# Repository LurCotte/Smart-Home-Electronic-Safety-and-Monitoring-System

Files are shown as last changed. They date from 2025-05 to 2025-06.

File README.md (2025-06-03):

# 🔌 Smart Home Electronic Safety and Monitoring System

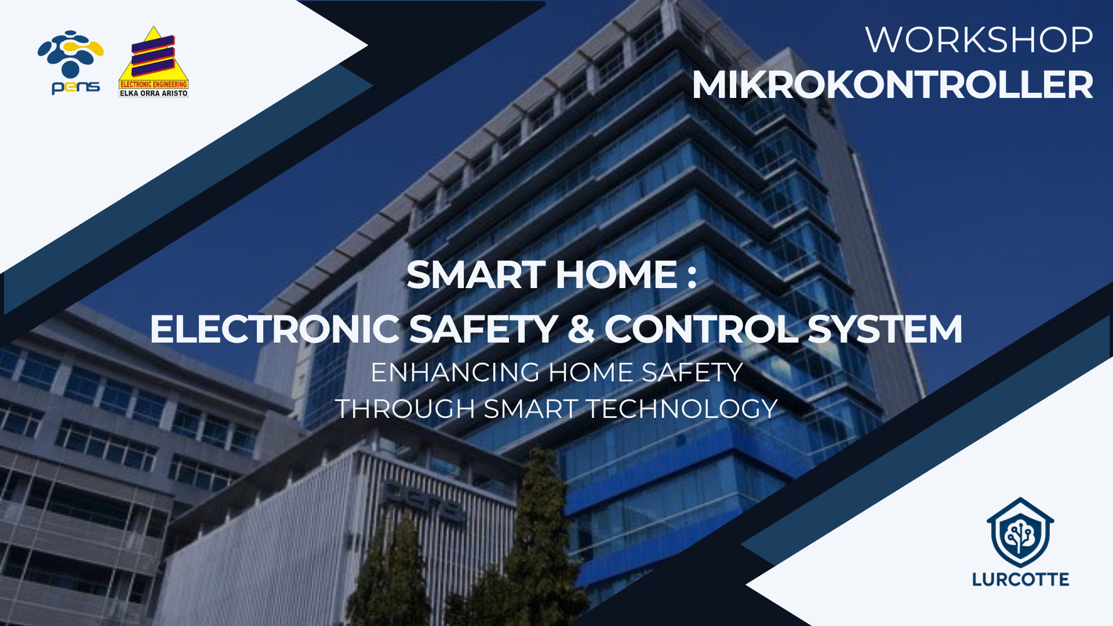
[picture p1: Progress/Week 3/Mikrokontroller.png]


## Team Member



## 📘 Deskripsi Proyek

Proyek ini bertujuan untuk mengembangkan **sistem automasi rumah pintar (Smart Home Automation System)** yang dapat memantau dan mengontrol peralatan elektronik secara real-time. Sistem ini juga dilengkapi dengan fitur **auto cut-off** untuk menjaga peralatan rumah tangga dari fluktuasi tegangan yang berasal dari jaringan listrik PLN.

## 🎯 Tujuan

- Mengontrol peralatan elektronik rumah secara dari satu titik pusat.
- Memantau konsumsi energi listrik dan menghitung biaya secara akurat.
- Melindungi perangkat dari overvoltage atau undervoltage melalui fitur auto cut-off.

## Video Iklan
https://vt.tiktok.com/ZSk2q9HfW/

## 🧠 Komponen Utama

| Komponen | Fungsi |
|---|---|
| Arduino Mega | Mikrokontroler utama yang mengatur komunikasi dan pengolahan data. |
| ACS712 | Sensor arus untuk mengukur konsumsi arus listrik. |
| ZMPT101B | Sensor tegangan AC untuk memantau tegangan dari sumber PLN. |
| Relay SPDT | Saklar untuk mengontrol perangkat listrik seperti lampu. |
| MCB 1 Phase | Proteksi arus lebih dan hubung singkat memutus aliran saat overload.  |
| Sensor Tambahan| Sensor-sensor lain untuk mendukung fungsi Smart Home tambahan. |

## 🔗 Komunikasi Sistem

Sistem menggunakan **komunikasi UART TTL** untuk mentransmisikan data antar perangkat dan sensor secara real-time. Arduino Mega memproses input dari sensor, lalu mengambil tindakan sesuai logika program.

## ⚡ Fitur Utama

- **Auto Cut-Off:** Memutus sambungan perangkat jika terjadi fluktuasi tegangan di luar ambang batas aman.
- **Monitoring Energi:** Penggunaan sensor ACS712 dan ZMPT101B untuk memantau konsumsi arus dan tegangan secara real-time.
- **Kontrol Perangkat Secara Terpusat:** Semua perangkat bisa dikontrol dari satu titik pusat melalui Komputer/laptop via UART.

## 🧩 Penjelasan Alur Sistem

- **Kabel fasa dan netral dari MCB PLN** terlebih dahulu masuk ke **input sensor ZMPT101B**. Sensor ini digunakan untuk membaca nilai tegangan dalam bentuk ADC (Analog to Digital Converter) yang kemudian akan diumpankan ke **pin analog mikrokontroler AVR**.

- **Mikrokontroler AVR** berkomunikasi dengan **laptop melalui komunikasi serial UART**, yang berfungsi sebagai antarmuka dan pusat kontrol untuk mengaktifkan atau menonaktifkan perangkat elektronik dari satu tempat.

- Pada **relay 5V**, pin **pole (common)** dihubungkan ke kabel fasa dari MCB PLN, pin **NO (Normally Open)** dihubungkan ke input MCB 1 phase, dan pin **coil** dihubungkan ke **pin output dari mikrokontroler AVR**.

- Jika **mikrokontroler AVR menerima perintah aktivasi dari laptop**, maka ia akan mengaktifkan pin output yang telah ditentukan, sehingga mengaktifkan relay dan menyebabkan perangkat elektronik menyala. Namun, hal ini hanya akan terjadi **jika tidak terdeteksi adanya fluktuasi tegangan atau hubung singkat**.

- **Perintah pengaktifan perangkat elektronik tidak akan diproses jika terjadi fluktuasi tegangan**, karena fungsi pendeteksi fluktuasi memiliki prioritas lebih tinggi. 

- Selain itu, jika terjadi **hubung singkat**, maka aktivasi perangkat tidak dapat dilakukan karena **MCB secara otomatis akan melakukan pemutusan arus (OFF)** untuk proteksi sistem.

- **Sensor ACS712** digunakan untuk membaca arus listrik yang kemudian akan digunakan untuk **perhitungan daya listrik (Watt)** secara real-time.

## 📊 Mind Map, Flowchart dan Diagram Blok

*Mind Map.*

Mind Map

*Flowchart.*

Flowchart Logika Kerja

*Diagram Blok Sistem.*

Diagram Hardware

*Tampilan GUI Python*

![Uploading 123.PNG…]()

## 🚀 Pengembangan Selanjutnya

- Integrasi dengan koneksi WiFi (ESP8266/ESP32) untuk kontrol via aplikasi mobile.
- Dashboard berbasis web untuk pemantauan konsumsi daya secara grafis.
- Otomatisasi berdasarkan waktu, cuaca, atau sensor gerak.

## 📁 Struktur Direktori (Opsional)
```bash
SmartHome-Automation/
│
├── src/                      # Kode program Arduino
├── images/                   # Diagram dan flowchart sistem
│   ├── block_diagram.png
│   └── flowchart_program.png
├── README.md                 # Dokumentasi proyek
└── docs/                     # Panduan penggunaan & pengembangan

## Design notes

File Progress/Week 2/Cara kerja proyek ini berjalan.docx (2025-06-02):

CARA KERJA

## 1. Sistem Awal & Setup

- Setelah sistem dinyalakan, Arduino Mega akan melakukan inisialisasi:
  - Mengatur pin sensor dan output (relay).
  - Menyiapkan komunikasi UART dengan laptop.
  - Menyiapkan ambang batas tegangan dan arus untuk proteksi.
- MCB PLN utama menyuplai listrik ke sistem (fase dan netral).

## 2. Pembacaan Data Sensor

### a. Sensor Tegangan (ZMPT101B)

- Membaca tegangan AC dari jaringan PLN.
- Tegangan diubah menjadi sinyal analog (0–5V) dan masuk ke pin analog Arduino.
- Arduino mengonversi data ADC menjadi nilai tegangan aktual (Volt).

### b. Sensor Arus (ACS712)

- Membaca arus yang mengalir ke perangkat rumah tangga.
- Arus dikonversi menjadi tegangan analog menggunakan efek Hall.
- Arduino membaca nilai ADC lalu menghitung arus aktual (Ampere).

## 3. Analisis & Proteksi Otomatis

Arduino menganalisis data sensor:

- Jika tegangan normal (misal 200V–240V) dan arus normal (misal < 6A):
  - Sistem dianggap aman → Siap aktifkan perangkat.
- Jika tegangan drop atau naik tajam (fluktuasi):
  - Sistem dianggap tidak aman → Relay tidak diaktifkan.
- Jika arus melebihi ambang batas (overload):
  - Arduino memutus relay → auto cut-off aktif.
- Jika terjadi short circuit:
  - MCB 1 Phase akan trip (OFF) dan memutus aliran listrik.
  - Arduino mendeteksi tidak ada arus → sistem dinonaktifkan.

## 4. Aktivasi Perangkat Elektronik

- Laptop mengirim perintah via UART: misalnya “AKTIFKAN”.
- Arduino akan memeriksa status tegangan & arus:
  - Jika aman, Arduino mengaktifkan relay SPDT (menghubungkan fase ke MCB 1 Phase).
  - Jika tidak aman, perintah diabaikan dan relay tetap OFF.

## 5. Monitoring Real-Time

- Arduino secara berkala mengirimkan data ke laptop:
  - Tegangan (Volt)
  - Arus (Ampere)
  - Daya (Watt = V × I)
  - Status sistem (AMAN / BAHAYA)
- Data bisa ditampilkan dalam bentuk teks atau grafik.

## 6. Kondisi Abnormal atau Emergency

- Jika sewaktu-waktu tegangan berubah drastis atau arus melonjak:
  - Arduino langsung mematikan relay (proteksi otomatis).
  - MCB 1 Phase memutus arus jika terdeteksi short circuit.
  - Sistem tidak bisa diaktifkan ulang sampai MCB dinyalakan manual.

## Kesimpulan Cara Kerja Sistem:

- Sistem mendeteksi, menganalisis, dan mengontrol perangkat elektronik secara otomatis dan real-time.
- Proteksi otomatis berbasis sensor dan MCB mencegah kerusakan peralatan.
- Kendali terpusat via laptop membuat sistem lebih fleksibel dan canggih.
- Kombinasi Arduino, sensor, relay, dan MCB menjadikan sistem ini efisien, aman, dan cocok untuk smart home masa kini.

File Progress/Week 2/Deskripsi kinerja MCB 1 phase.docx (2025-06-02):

### Deskripsi Komponen: MCB 1 Phase

MCB (Miniature Circuit Breaker) 1 Phase adalah komponen proteksi listrik yang berfungsi memutus arus listrik secara otomatis jika terjadi:

- Kelebihan arus (overload)
- Hubung singkat (short circuit)

Dalam sistem, MCB berperan sebagai proteksi lapisan terakhir terhadap kondisi berbahaya, melengkapi proteksi otomatis dari Arduino dan relay.

Fungsi MCB 1 Phase dalam system :

1. Memutus Arus Saat Bahaya:
  - Jika arus melebihi kapasitas (misal >6A untuk MCB 6A), MCB akan trip (OFF) secara otomatis.
  - Jika terjadi short circuit, MCB langsung memutus jalur fasa dalam waktu milidetik.
2. Melindungi Perangkat Rumah Tangga:
  - Mencegah kerusakan perangkat akibat arus berlebih.
  - Mencegah potensi kebakaran akibat korsleting listrik.
3. Integrasi dengan Sistem Otomatis:
  - Ditempatkan setelah output relay dan sebelum perangkat elektronik.
  - Jika MCB trip, Arduino akan mendeteksi bahwa tidak ada arus atau status sistem OFF, dan menonaktifkan relay untuk mencegah percikan listrik saat recovery.

### Kelebihan MCB:

- Cepat merespon bahaya listrik
- Mudah di-reset secara manual
- Tidak perlu diganti setelah trip (beda dengan sekering)
- Menjadi proteksi akhir jika kontrol otomatis gagal

### Contoh Kinerja MCB dalam Proyekmu:

Misalnya:

1. Arduino mendeteksi arus 2A dan tegangan 220V → relay ON.
2. Perangkat menyala, lalu terjadi korsleting karena kabel rusak.
3. Arus melonjak menjadi 15A dalam waktu singkat.
4. MCB 6A langsung memutus arus, sistem menjadi aman.
5. Arduino membaca arus = 0A → menandakan bahwa MCB OFF.
6. Sistem tidak mengaktifkan ulang perangkat sebelum dicek ulang manual.

### Kesimpulan:

MCB 1 Phase adalah komponen penting dan wajib dalam sistem smart home berbasis Arduino. Meskipun sistem sudah otomatis (menggunakan sensor dan relay), MCB menjadi pertahanan terakhir jika terjadi kondisi darurat kelistrikan. Ia menjaga agar tidak ada arus berbahaya yang mengalir ke perangkat dan rumah — sehingga keselamatan tetap terjaga

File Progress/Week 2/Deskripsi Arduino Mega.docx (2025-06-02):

Deskripsi Komponen: Arduino Mega 2560

Arduino Mega berperan sebagai otak utama sistem. Semua proses pengambilan data, pengambilan keputusan, serta kontrol perangkat elektronik dilakukan oleh mikrokontroler ini. Karena memiliki banyak pin I/O dan memori besar, Arduino Mega sangat cocok untuk proyek kompleks seperti smart home yang melibatkan banyak sensor dan aktuator.

Fungsi utama Arduino Mega :

1. Membaca Sensor:
  - Menerima data tegangan dari sensor ZMPT101B (pin analog).
  - Menerima data arus listrik dari ACS712 (pin analog).
  - Dapat membaca sensor tambahan (LDR, suhu, PIR, dll) jika diperlukan.
2. Memproses Data:
  - Mengubah sinyal analog dari sensor menjadi data numerik.
  - Menghitung nilai tegangan, arus, dan daya (Watt).
  - Membandingkan nilai tersebut dengan ambang batas aman.
3. Mengambil Keputusan:
  - Jika tegangan dan arus normal, Arduino mengaktifkan relay untuk menyalakan perangkat.
  - Jika tegangan tidak stabil (drop/spike) atau arus berlebih, Arduino menonaktifkan relay (cut-off).
  - Jika terjadi short circuit dan MCB trip, Arduino mendeteksi perubahan status dan mematikan sistem untuk proteksi.
4. Kontrol Aktuator:
  - Memberi sinyal ke relay SPDT (melalui pin digital) untuk ON/OFF arus ke peralatan.
  - Dapat dikembangkan untuk mengontrol lampu, kipas, charger, dll.
5. Komunikasi Serial ke Laptop (UART):
  - Mengirim data real-time seperti:
    - Tegangan (Volt)
    - Arus (Ampere)
    - Daya (Watt)
    - Status sistem (ON/OFF, Aman/Bahaya)
  - Menerima perintah aktivasi dari laptop (misal: menyalakan atau mematikan perangkat).
  - Dapat digunakan untuk logging data atau visualisasi grafik.\

Peran Arduino Mega :

- Menjadi pusat keputusan proteksi otomatis (cut-off saat kondisi berbahaya).
- Memastikan keamanan perangkat elektronik dan penghuni rumah.
- Bisa dikembangkan lebih lanjut untuk integrasi IoT (dengan modul ESP8266/ESP32 sebagai penghubung).

Contoh proses :

1. Arduino membaca tegangan = 230V → OK.
2. Arduino membaca arus = 2.3A → OK.
3. Arduino hitung daya = 529W → OK.
4. Arduino menerima perintah ON → Mengaktifkan relay.
5. Jika tiba-tiba tegangan drop ke 170V → Arduino OFF-kan relay → Sistem terlindungi.

Kesimpulan :

Arduino Mega bertindak sebagai unit pusat pengontrol dan pengolah data. Ia mengoordinasikan semua komponen mulai dari sensor input, pengambilan keputusan berbasis logika keamanan, hingga eksekusi kontrol terhadap perangkat elektronik. Arduino Mega memastikan sistem smart home ini menjadi otomatis, aman, dan dapat dimonitor secara real-time.

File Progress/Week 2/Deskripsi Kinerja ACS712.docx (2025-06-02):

Deskripsi Komponen: ACS712 dalam Sistem

Sensor ACS712 merupakan sensor arus berbasis efek Hall yang digunakan untuk mengukur arus listrik AC maupun DC secara aman dan real-time. Dalam sistemmu, ACS712 berfungsi untuk memantau arus konsumsi listrik dari peralatan rumah tangga yang sedang menyala. Data arus ini kemudian digunakan untuk:

- Menghitung daya listrik (dengan kombinasi data tegangan dari ZMPT101B).
- Melakukan proteksi terhadap arus berlebih (overload).
- Monitoring status konsumsi daya secara serial ke laptop.

Fungsi utama dalam system :

- Mengukur besar arus yang mengalir melalui jalur fasa setelah relay dan sebelum perangkat elektronik.
- Menghasilkan tegangan analog (sekitar 0–5V) yang proporsional terhadap arus yang mengalir.
- Memberikan input ke pin analog Arduino (misal A1) untuk diolah dan dianalisis.
- Jika arus melebihi ambang batas aman, sistem akan menonaktifkan relay (cut-off otomatis).

Cara kerja ACS712 :

1. Arus listrik dari fasa melewati jalur input/output di sensor ACS712.
2. Efek Hall di dalam sensor mendeteksi medan magnet yang muncul akibat arus, lalu mengubahnya menjadi tegangan analog.
3. Tegangan ini biasanya berpusat di 2.5V saat arus = 0A.
4. Arduino membaca nilai tegangan analog, lalu menghitung arus aktual (positif/negatif).
5. Nilai arus digunakan untuk:
  - Menghitung daya (Watt) → daya = arus × tegangan.
  - Proteksi → jika arus melebihi ambang batas, maka sistem memutus aliran (relay OFF).

Kelebihan penggunaan ACS712 :

- Dapat mengukur arus AC dan DC (meskipun proyekmu fokus ke AC).
- Aman karena tidak menghubungkan langsung kabel ke ADC, hanya sinyal tegangan.
- Ukuran kompak dan langsung kompatibel dengan Arduino.
- Tersedia dalam beberapa varian: 5A, 20A, 30A (dengan sensitivitas berbeda).

Kesimpulan peran ACS712 :

Sensor ini berperan penting dalam deteksi arus aktual, perhitungan konsumsi daya, serta fungsi proteksi arus lebih. Dengan ACS712, sistem bisa memastikan perangkat tidak digunakan melebihi kapasitas, dan memutus aliran jika arus yang terdeteksi tidak wajar — mencegah risiko kebakaran atau kerusakan peralatan.

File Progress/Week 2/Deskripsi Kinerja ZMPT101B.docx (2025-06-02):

Deskripsi Komponen: ZMPT101B dalam Sistem

Sensor ZMPT101B merupakan sensor yang dirancang khusus untuk mengukur tegangan AC dari jaringan listrik (seperti PLN) secara aman dan terisolasi. Dalam sistem ini, ZMPT101B digunakan untuk memantau fluktuasi tegangan secara real-time, sehingga sistem dapat mengambil keputusan otomatis untuk mengaktifkan atau menonaktifkan perangkat elektronik demi keselamatan.

Fungsi utama dalam system :

- Mengukur tegangan AC PLN (biasanya 220V) dan mengubahnya menjadi sinyal analog (0–5V).
- Memberikan input analog ke mikrokontroler (Arduino Mega) melalui pin analog (misal A0).
- Data tegangan digunakan untuk:
  - Monitoring di laptop melalui komunikasi UART.
  - Logika auto cut-off: memutus aliran listrik ke perangkat jika tegangan di luar batas aman (misalnya <180V atau >250V)

Cara kerja ZMPT101B :

1. Kabel fasa dan netral dari MCB PLN disambungkan ke input sensor ZMPT101B.
2. ZMPT menggunakan trafo kecil di dalamnya untuk menurunkan tegangan AC tinggi menjadi sinyal AC rendah.
3. Sinyal ini kemudian diolah oleh rangkaian pembagi tegangan dan penyearah untuk menghasilkan sinyal analog yang bisa dibaca oleh pin ADC Arduino.
4. Arduino membaca nilai ADC, lalu menghitung nilai tegangan aktual dengan rumus kalibrasi.
5. Nilai ini digunakan untuk monitoring, serta sebagai syarat pengaktifan relay (hanya jika tegangan dalam batas normal).

Kelebihan penggunaan ZMPT101B :

- Aman: Terisolasi dari tegangan tinggi (pakai trafo isolasi).
- Akurasi cukup baik untuk aplikasi monitoring rumah tangga.
- Output linier yang cocok untuk pembacaan ADC oleh mikrokontroler.
- Mudah dikalibrasi dan kompatibel langsung dengan Arduino.

Kesimpulan peran ZMPT101B :

Sensor ini berperan kritis sebagai detektor kesehatan tegangan dari jaringan listrik PLN. Tanpa sensor ini, sistem tidak dapat mendeteksi fluktuasi yang berbahaya dan berpotensi merusak perangkat rumah tangga. Dengan ZMPT101B, sistem menjadi lebih cerdas dan aman karena dapat mengambil tindakan preventif secara otomatis.

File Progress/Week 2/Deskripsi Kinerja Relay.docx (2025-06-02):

Deskripsi Komponen: Relay SPDT dalam Sistem

Relay SPDT (Single Pole Double Throw) berperan penting sebagai saklar elektronik dalam sistem ini. Komponen ini memungkinkan Arduino Mega untuk mengontrol sambungan atau pemutusan aliran listrik ke peralatan rumah tangga secara otomatis berdasarkan hasil pemantauan tegangan dan arus.

#### Fungsi dalam Sistem:

Relay berfungsi sebagai penghubung atau pemutus jalur fasa dari sumber listrik ke perangkat elektronik yang akan dikendalikan. Dengan kontrol dari mikrokontroler, relay memastikan bahwa peralatan hanya menyala ketika kondisi listrik aman (tegangan stabil dan tidak ada arus lebih).

#### Konfigurasi Koneksi:

- Pin COM (Common / Pole): Terhubung ke kabel fasa dari MCB PLN.
- Pin NO (Normally Open): Terhubung ke input MCB 1 phase, yang kemudian mengalirkan listrik ke perangkat rumah tangga.
- Pin NC (Normally Closed): Tidak digunakan dalam sistem ini.
- Pin Coil (+/-): Terhubung ke pin digital Arduino Mega (untuk kendali ON/OFF), dan satu sisi ke GND atau sumber 5V (melalui transistor jika perlu).

#### Cara Kerja di Sistem:

1. Saat Arduino tidak memberi sinyal, kontak COM dan NO terputus, sehingga arus tidak mengalir ke perangkat.
2. Jika tegangan dan arus terdeteksi dalam kondisi normal, dan perintah aktivasi diterima dari laptop, Arduino mengirimkan sinyal ke coil relay.
3. Relay pun menutup kontak antara COM dan NO, menyebabkan arus mengalir ke perangkat elektronik.
4. Jika terjadi fluktuasi tegangan atau hubung singkat, Arduino menonaktifkan relay, memutuskan aliran listrik secara otomatis demi proteksi sistem.

#### Keunggulan Penggunaan Relay SPDT:

- Mampu mengontrol beban AC dari sinyal logika DC (dari Arduino).
- Memberi isolasi antara rangkaian kontrol (low voltage) dan daya tinggi (PLN).
- Dapat diatur secara otomatis berdasarkan logika kondisi sistem (aman/tidak aman).
- Fail-safe: Jika tidak ada sinyal (misal Arduino mati), perangkat tetap dalam kondisi mati karena jalur NO terbuka.

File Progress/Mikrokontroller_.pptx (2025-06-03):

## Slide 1

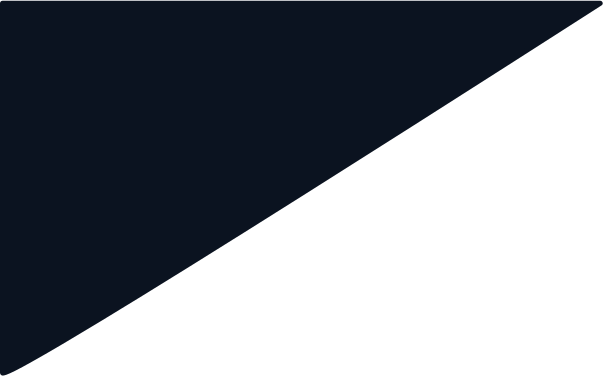
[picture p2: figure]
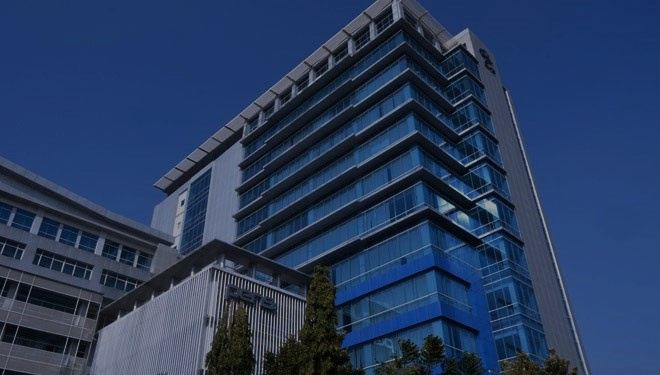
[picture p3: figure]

SMART HOME :
ELECTRONIC SAFETY & CONTROL SYSTEM

ENHANCING HOME SAFETY THROUGH SMART TECHNOLOGY

WORKSHOP

MIKROKONTROLLER

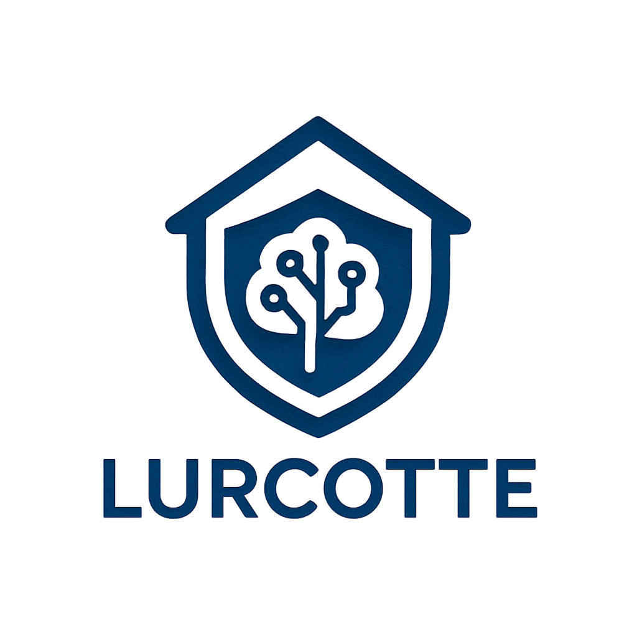
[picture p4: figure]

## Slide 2

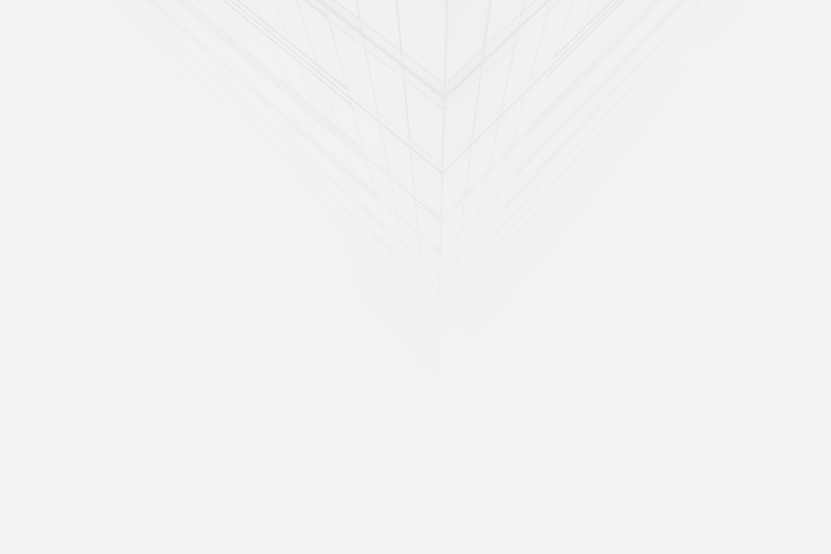
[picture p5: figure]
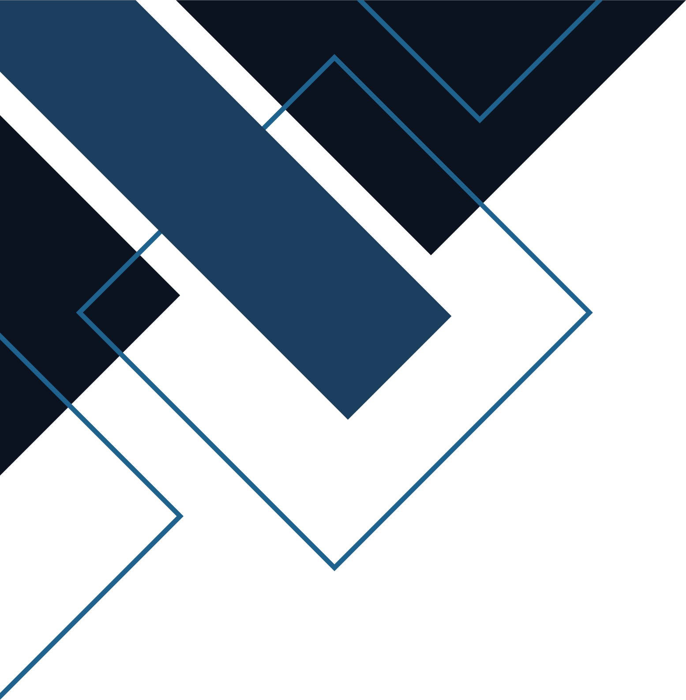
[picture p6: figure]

DOSEN PEMBIMBING

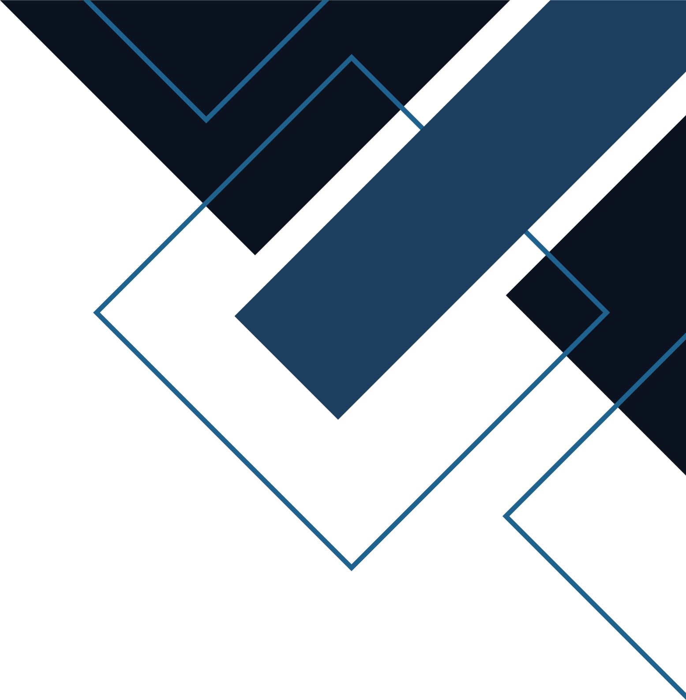
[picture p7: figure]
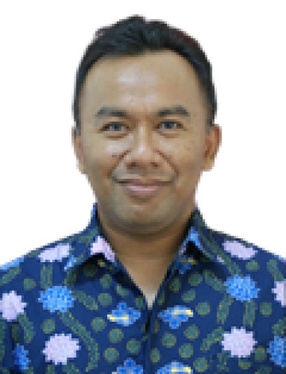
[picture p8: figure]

AKHMAD HENDRIAWAN, S.T, M.T
197501272002121003

LURCOTTE MEMBER

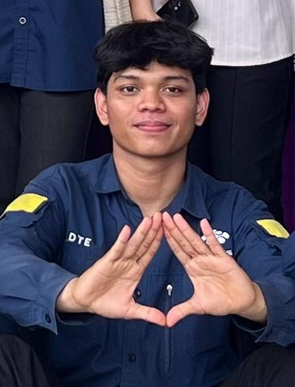
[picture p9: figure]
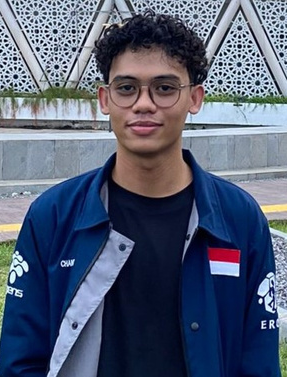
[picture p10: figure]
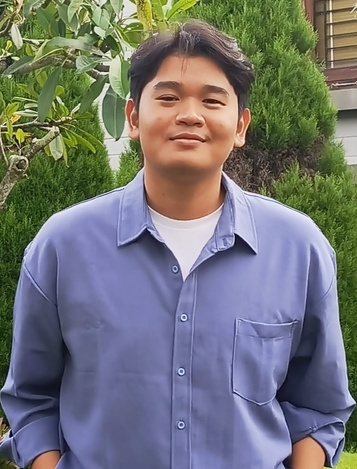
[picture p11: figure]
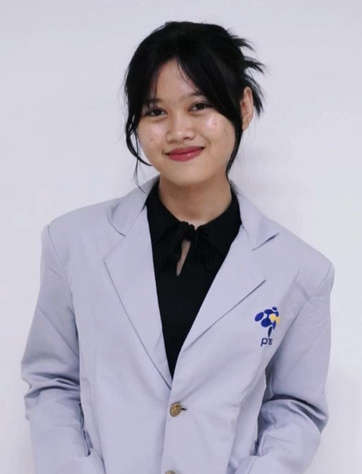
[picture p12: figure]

DICKY ANANDA PRAMUDITA
AS
HARDWARE DEVELOPER

CHANDRA NUR ISMAIL
AS
3D & PCB DESIGNER

M. IQBAL HAKIM
AS
PROJECT MANAGER

MAULANA ACHMAD HIDAYATULLOH AS
SOFTWARE DEVELOPER

MAULYD’DINA NUR MAY FIROH
AS
NON-TECH / UI & UX DESIGNER

ENHANCING

HOME SAFETY

THROUGH SMART TECHNOLOGY

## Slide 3

LATAR BELAKANG

Fluktuasi tegangan listrik bisa merusak perangkat elektronik

Rumah belum memiliki sistem proteksi otomatis

Belum ada pemantauan pemakaian listrik secara real-time

01

02

03

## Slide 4

RUMUSAN MASALAH

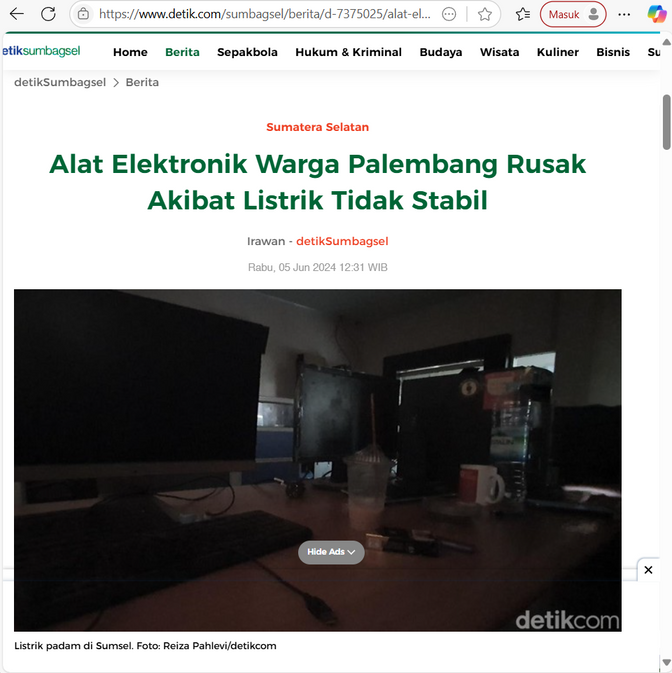
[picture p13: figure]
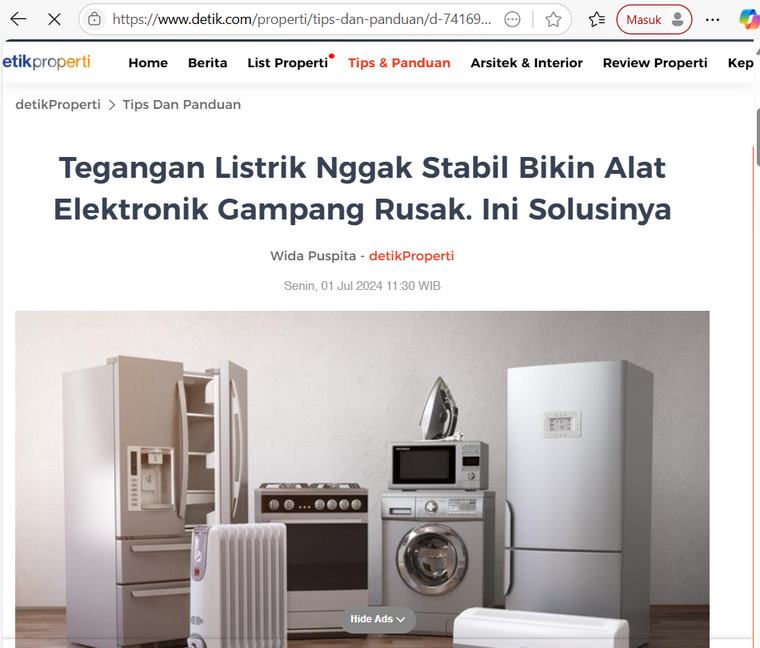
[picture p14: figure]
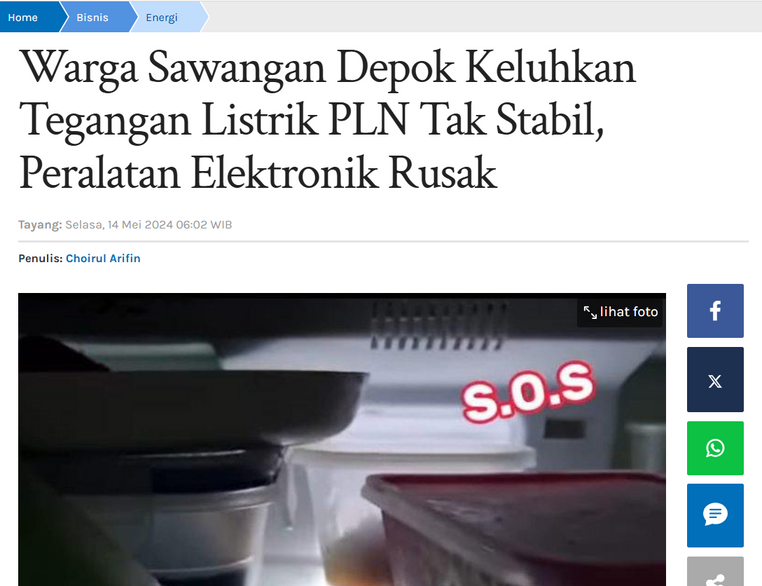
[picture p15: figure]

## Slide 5

TUJUAN

Mencegah kerusakan akibat tegangan tidak stabil

Monitoring kondisi listrik rumah secara real-time

Mengontrol perangkat elektronik secara otomatis

01

02

03

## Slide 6

UI/UX DESIGN

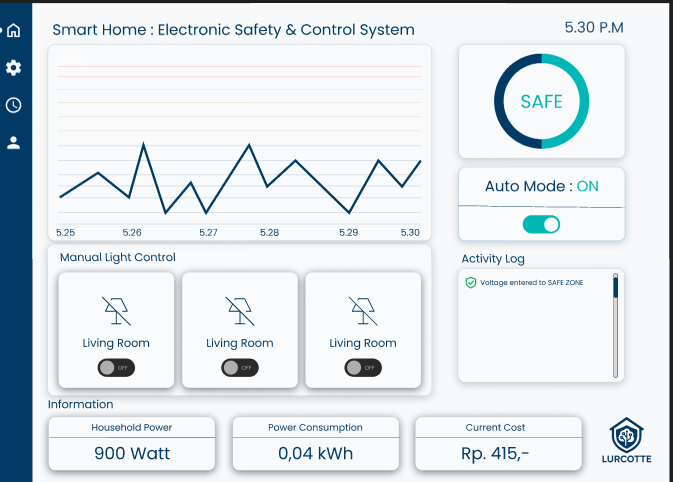
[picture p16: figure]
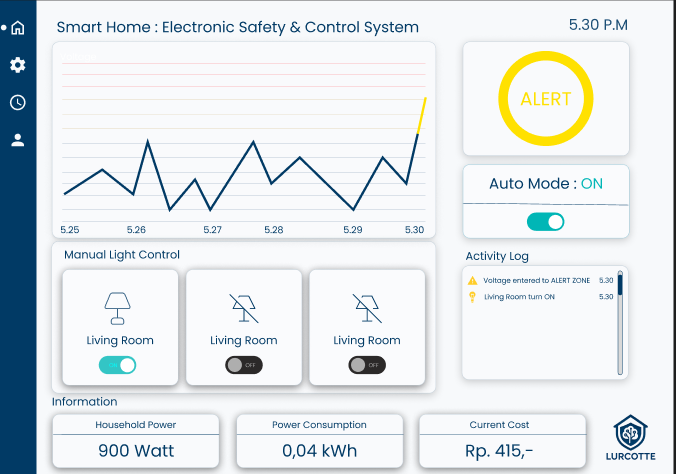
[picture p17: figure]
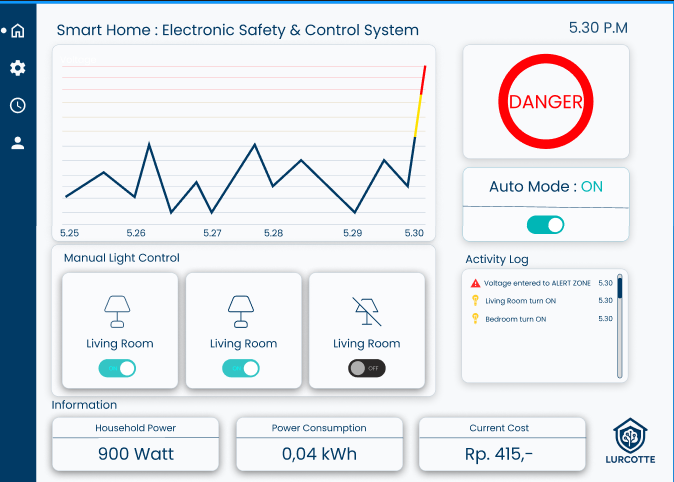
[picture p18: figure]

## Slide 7

3D DESIGN

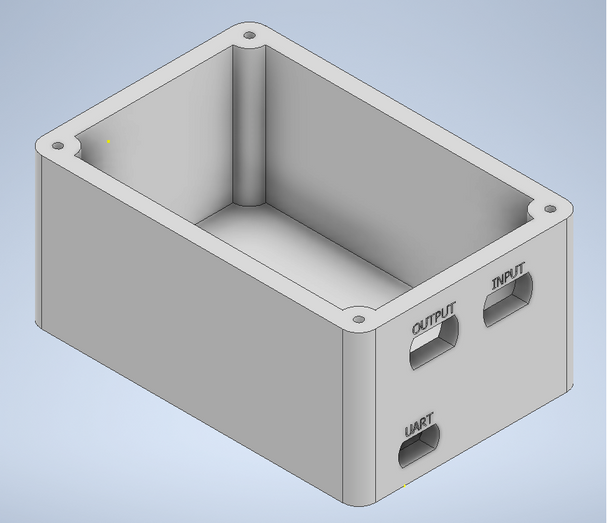
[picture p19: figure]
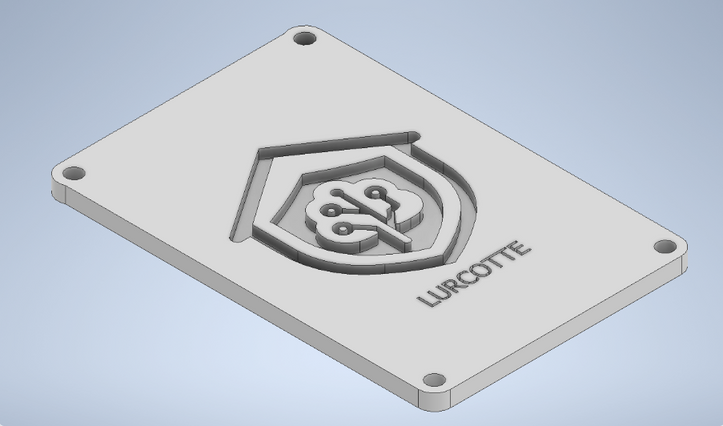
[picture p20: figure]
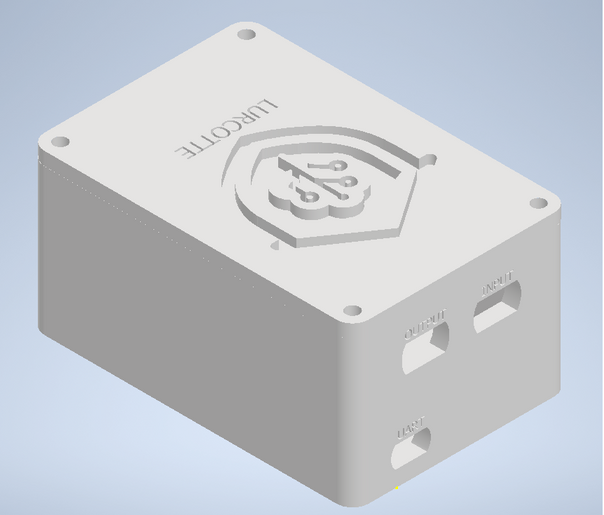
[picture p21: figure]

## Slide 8

SKEMATIK & PCB DESIGN

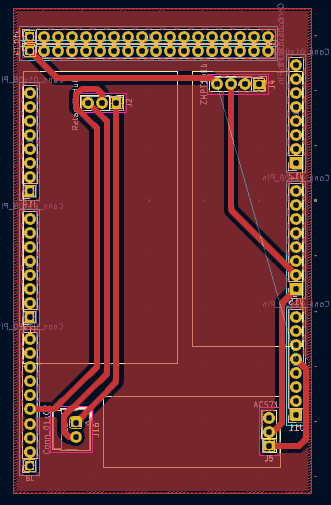
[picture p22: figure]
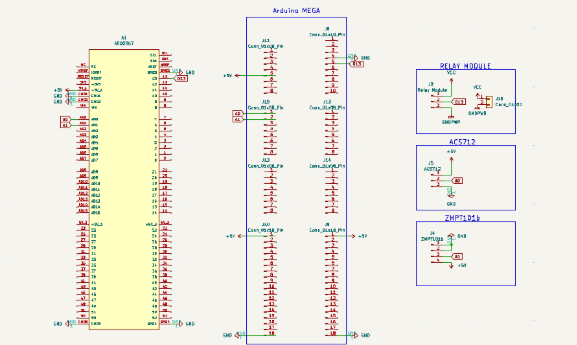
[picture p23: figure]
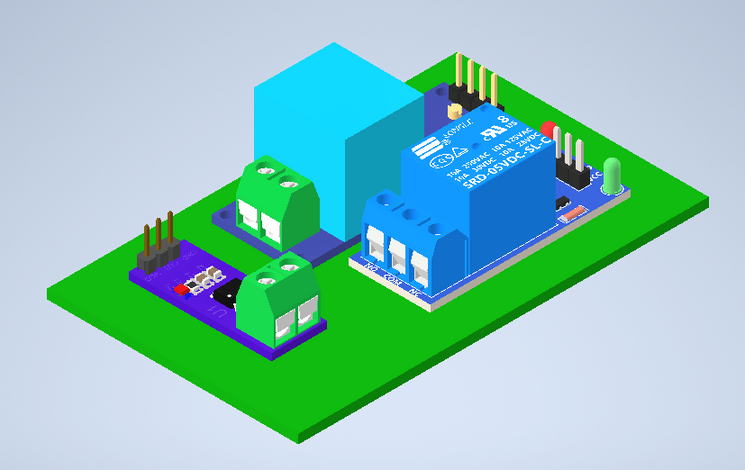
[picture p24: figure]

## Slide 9

PCB HARDWARE

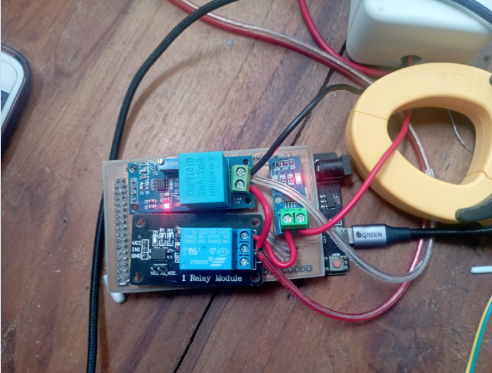
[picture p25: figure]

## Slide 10

HASIL PENGUJIAN

01

Sistem berhasil memproteksi & monitoring

Efisien dan user-friendly

Bisa dikembangkan ke level smart energy management

02

03

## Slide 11

TERIMA KASIH

Link Video Pendek :
https://drive.google.com/file/d/1bdyQihNFbl6OnL9QvR1Q_Gj12umeS__x/view?usp=drivesdk

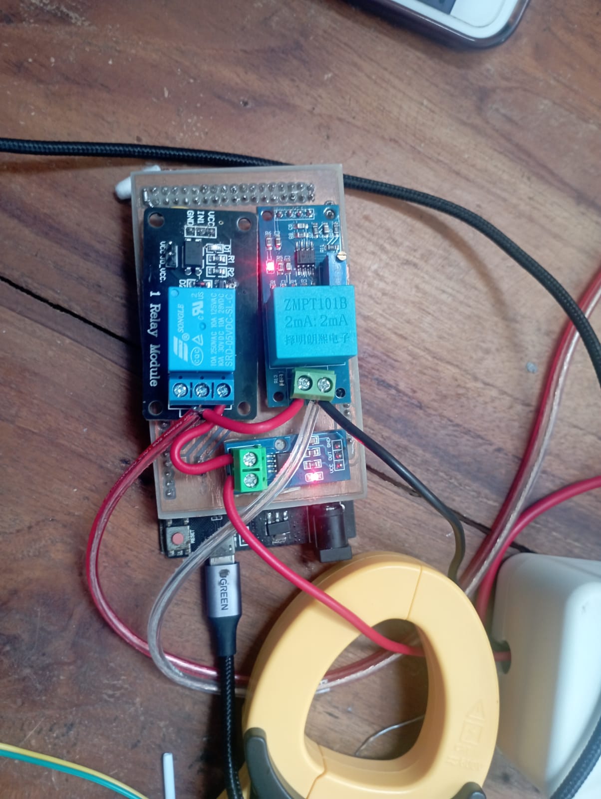
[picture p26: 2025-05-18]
Hardware/Hardware pcb.jpeg

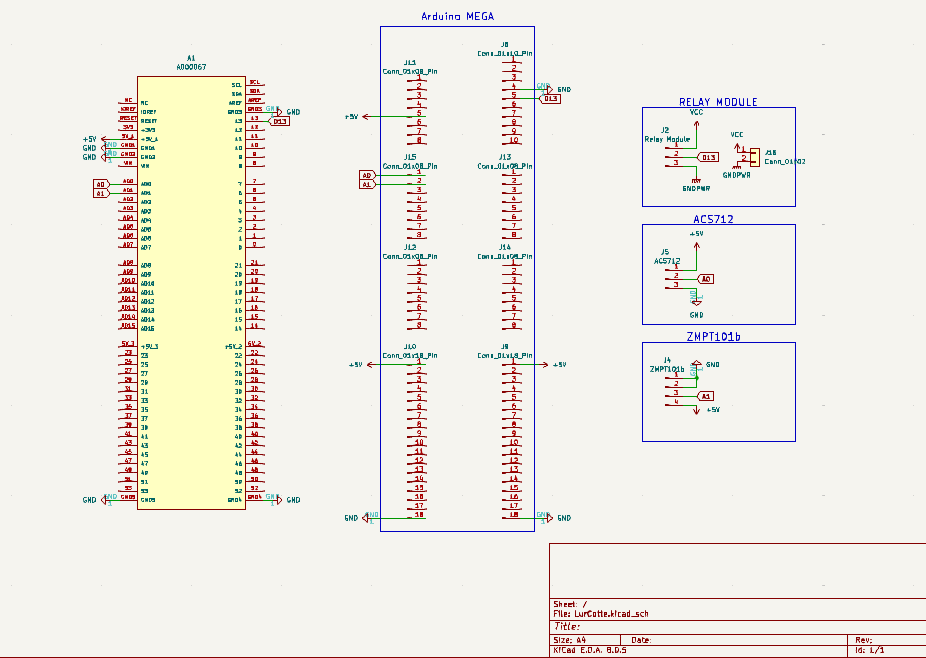
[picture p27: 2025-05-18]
Hardware/LurCotte.png

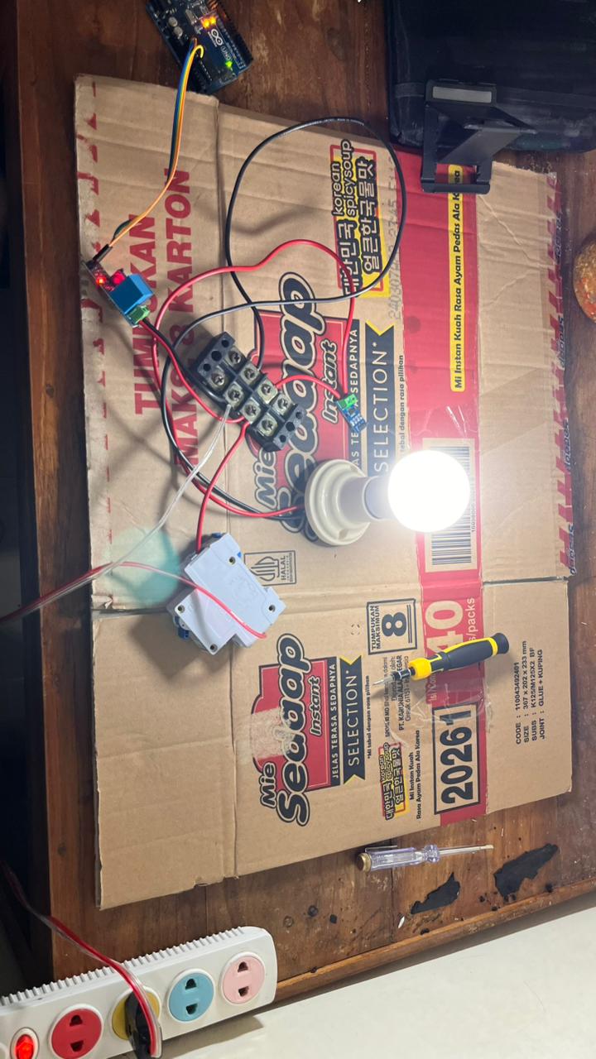
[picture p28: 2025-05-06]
Progress/Week 3/Uji coba alat.jpeg

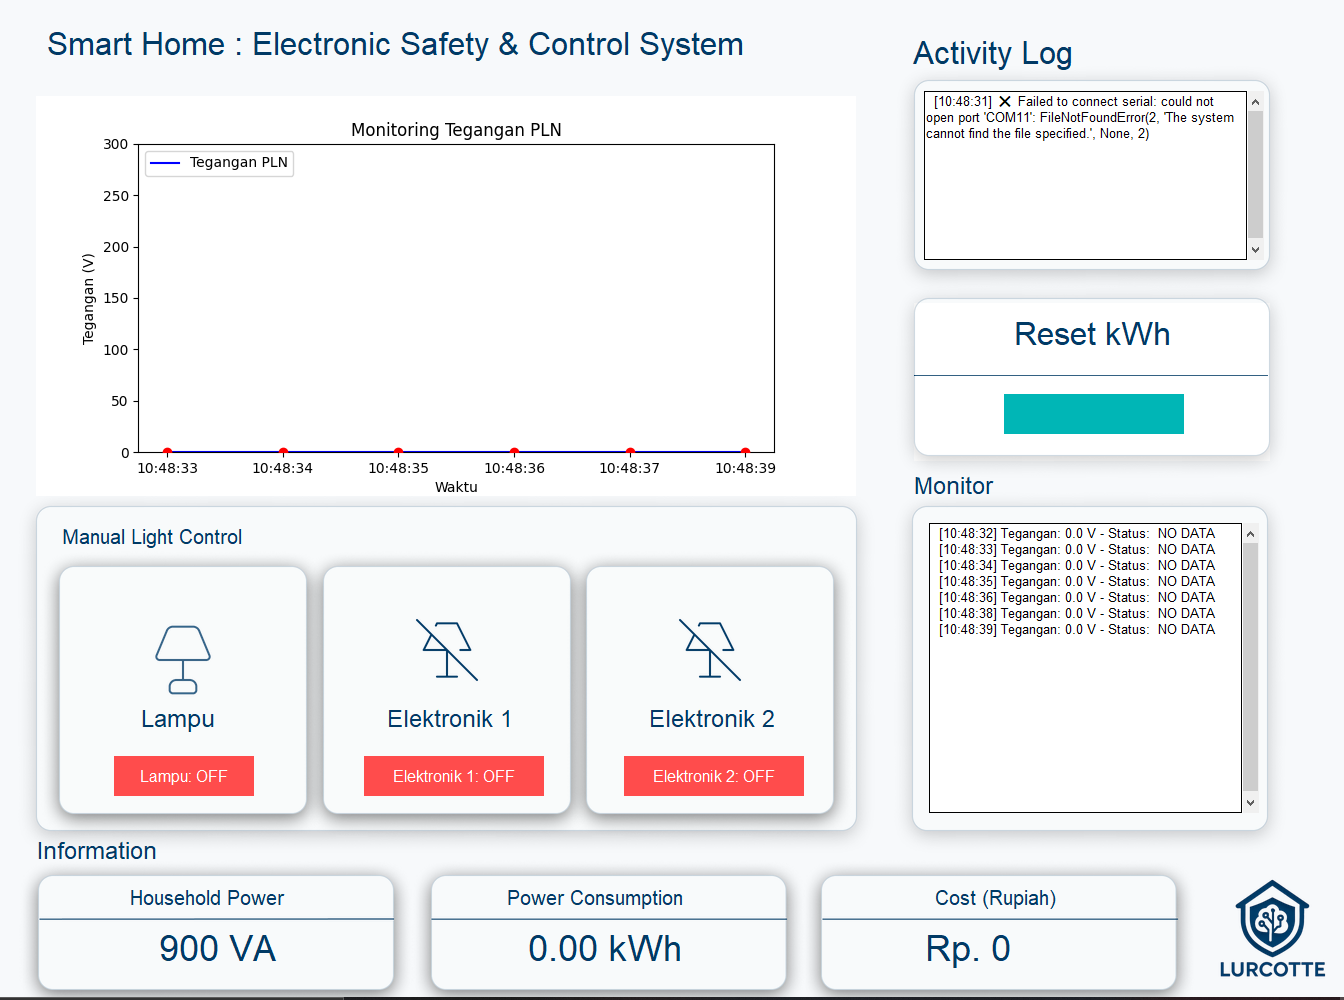
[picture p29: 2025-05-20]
Progress/Week 4/Lurcotte GUI.PNG

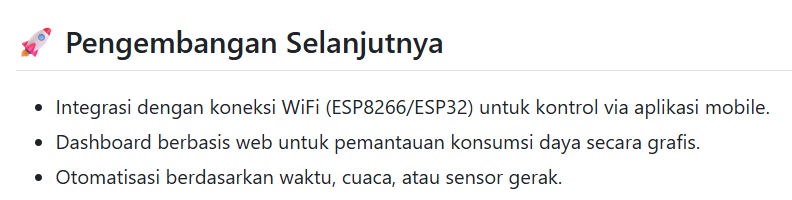
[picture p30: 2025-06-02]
Progress/Week 1/Pengembangan selanjutnya.png

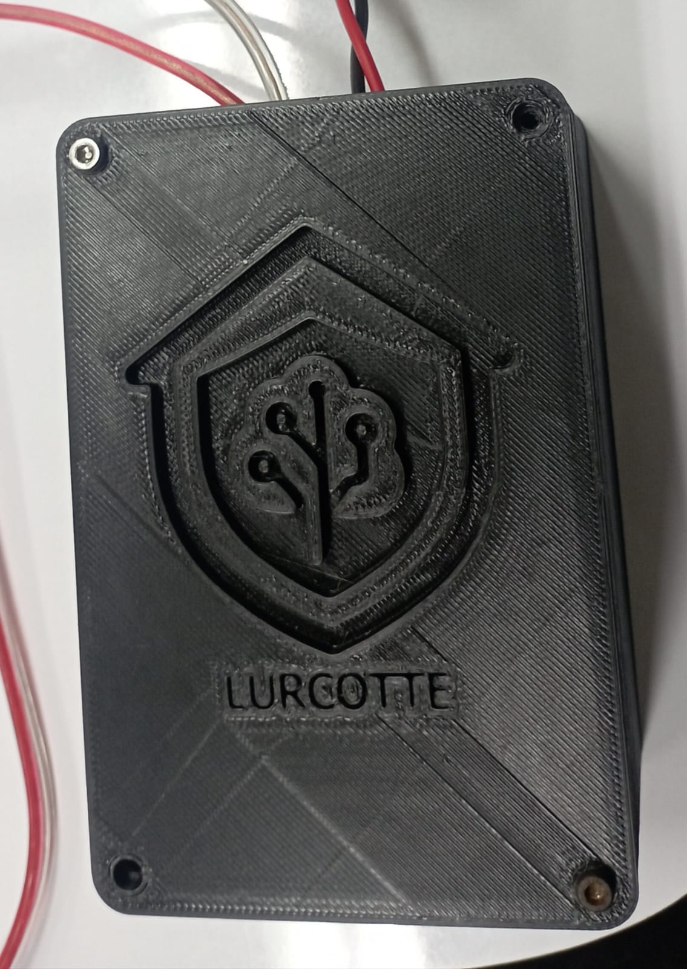
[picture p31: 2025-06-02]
Progress/Week 5/Hasil3D.jpeg

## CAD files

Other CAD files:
Progress/Week 4/BOX Lurcotte.ipt
Progress/Week 4/Cover Lurcotte.ipt
Progress/Week 4/Lucotte BOX.iam

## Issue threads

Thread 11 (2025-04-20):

Melakukan reset terhadap sistem auto cut-off

DickyAnandaPramudita, 2025-04-20:

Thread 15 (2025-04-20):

Reset  kontrol perangkat secara terpusat dari laptop menggunakan komunikasi UART

MuhammadIqbalHakim, 2025-04-20:
Mengontrol banyak perangkat dari satu laptop lewat UART ke mikrokontroler avr

1. Gunakan perintah berbeda dari laptop, misalnya

- 'A' → Nyalakan Relay 1

- 'a' → Matikan Relay 1

- 'B' → Nyalakan Relay 2

- 'b' → Matikan Relay 2

dan seterusnya…

2.  Proses Komunikasi Trigger dari Laptop ke AVR

- Laptop Kirim Data Serial:

Laptop (misalnya dengan Python, aplikasi GUI, terminal serial, atau software seperti RealTerm / PuTTY) akan mengirim karakter atau perintah melalui port serial (COMx).

Contoh: Kirim 'A' untuk menyalakan relay 1.

- Data Masuk ke UART Mikrokontroler:

Di sisi AVR, UART akan menangkap data tersebut melalui register UDR0.

Ketika ada data masuk, flag RXC0 akan aktif.

- AVR Baca dan Eksekusi Perintah:

Program AVR akan membaca data itu dan melakukan sesuatu berdasarkan perintahnya (misalnya menyalakan GPIO untuk relay).

Contoh Skema Relay:

- Relay 1 → PB0

- Relay 2 → PB1

- Relay 3 → PB2

- Relay 4 → PB3

...hingga sebanyak yang kamu perlukan dan sesuai pin yang tersedia.

Contoh Kode Program:

#include <avr/io.h>
#include <util/delay.h>

void UART_Init(void) {
    uint16_t ubrr = 103; // 9600 bps @ 16MHz
    UBRR0H = (ubrr >> 8);
    UBRR0L = ubrr;
    UCSR0B = (1 << RXEN0) | (1 << TXEN0);  // Enable RX & TX
    UCSR0C = (1 << UCSZ01) | (1 << UCSZ00); // 8-bit data
}

char UART_Receive(void) {
    while (!(UCSR0A & (1 << RXC0)));
    return UDR0;
}

void Relay_Init(void) {
    DDRB |= 0x0F; // Set PB0-PB3 sebagai output untuk 4 relay
}

int main(void) {
    UART_Init();
    Relay_Init();

    while (1) {
        char cmd = UART_Receive();

        switch (cmd) {
            case 'A': PORTB |= (1 << PB0); break; // Relay 1 ON
            case 'a': PORTB &= ~(1 << PB0); break; // Relay 1 OFF
            case 'B': PORTB |= (1 << PB1); break; // Relay 2 ON
            case 'b': PORTB &= ~(1 << PB1); break; // Relay 2 OFF
            case 'C': PORTB |= (1 << PB2); break; // Relay 3 ON
            case 'c': PORTB &= ~(1 << PB2); break; // Relay 3 OFF
            case 'D': PORTB |= (1 << PB3); break; // Relay 4 ON
            case 'd': PORTB &= ~(1 << PB3); break; // Relay 4 OFF
            default: break;
        }
    }
}

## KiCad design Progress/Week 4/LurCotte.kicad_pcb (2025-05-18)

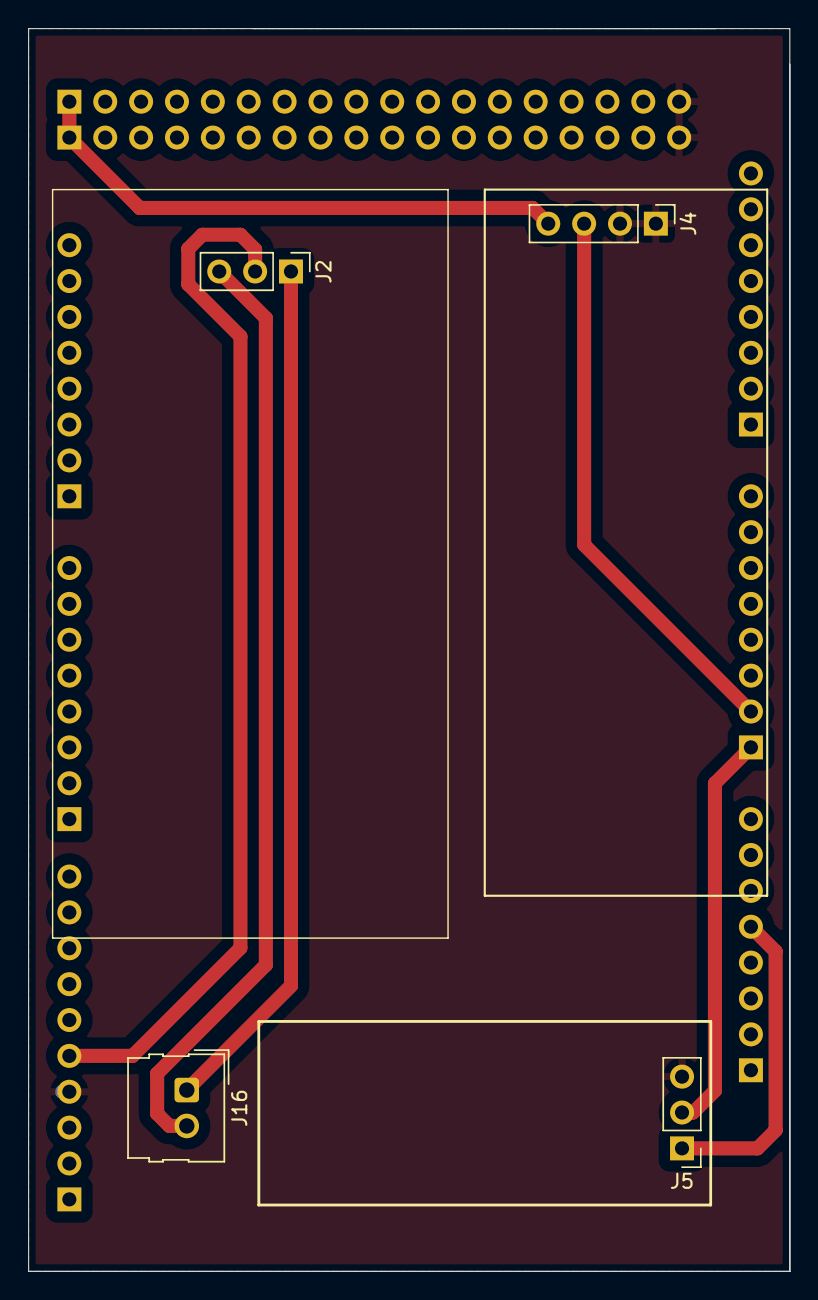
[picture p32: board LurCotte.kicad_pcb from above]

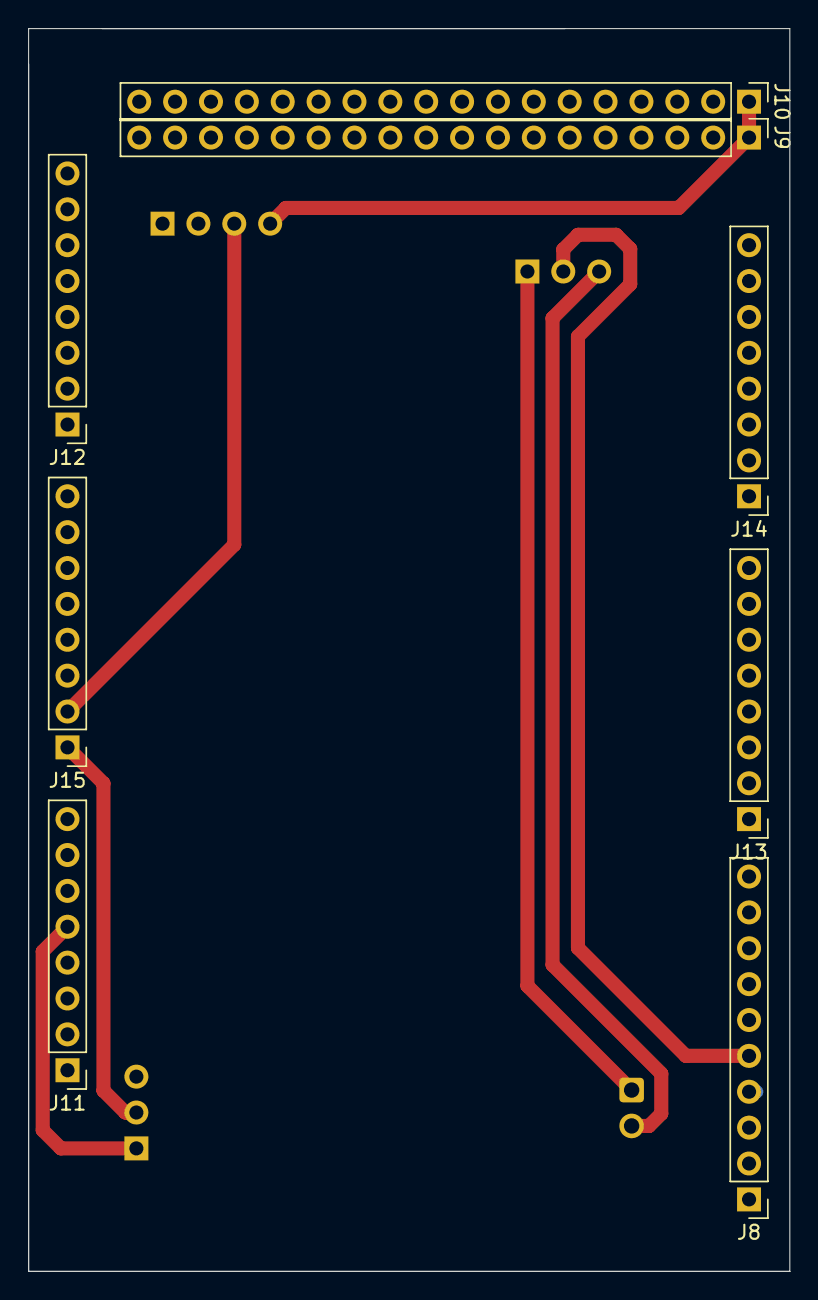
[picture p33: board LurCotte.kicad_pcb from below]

Board: 2 copper layers, 53.9 x 88.0 mm, 12 parts (8 on the bottom side), 7 nets.

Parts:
J2: Relay Module; PinHeader_1x03_P2.54mm_Vertical
J4: ZMPT101b; PinHeader_1x04_P2.54mm_Vertical
J5: ACS712; PinHeader_1x03_P2.54mm_Vertical
J8: Conn_01x10_Pin; PinHeader_1x10_P2.54mm_Vertical
J9, J10: Conn_01x18_Pin; PinHeader_1x18_P2.54mm_Vertical
J11, J12, J13, J14, J15: Conn_01x08_Pin; PinHeader_1x08_P2.54mm_Vertical
J16: Conn_01x02; Molex_SL_171971-0002_1x02_P2.54mm_Vertical

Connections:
+5V: J4.4, J5.1, J9.1, J10.1, J11.5
A0: J5.2, J15.1
A1: J4.3, J15.2
D13: J2.2, J8.5
GND: J4.1, J4.2, J5.3, J8.4, J9.18, J10.18
GNDPWR: J2.3, J16.2
VCC: J2.1, J16.1

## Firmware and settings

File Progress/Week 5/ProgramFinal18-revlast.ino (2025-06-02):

#include <avr/io.h>
#include <EEPROM.h>

const int pinRelay = 13;
const int interval = 20; // Interval sampling 20ms
const int durasiPemulihan = 10000; // Waktu pemulihan 10 detik
const int jumlahSampel = durasiPemulihan / interval;

const float batas_undervoltage = 150.0;
const float batas_overvoltage = 250.0;
const float batas_fluktuasi = 100.0;
const float batas_arus_short = 3.0;
const float tarif_per_kwh = 1352.0;

float vrms = 0;
float vrms_sebelumnya = 0;
float irms = 0;
float daya = 0;
float energi_kwh = 0;
float biaya_rupiah = 0;
float energi_kwh_terakhir = 0;

unsigned long startMillis;
bool proteksiAktif = false;

struct StatusPemulihan {
  bool teganganBaik;
  bool arusBaik;
};

StatusPemulihan statusBaik[jumlahSampel];
int indeksBuffer = 0;
bool dalamPemulihan = false;

void simpanEEPROM() {
  EEPROM.put(0, energi_kwh);
  EEPROM.put(sizeof(float), biaya_rupiah);
}

void muatEEPROM() {
  EEPROM.get(0, energi_kwh);
  EEPROM.get(sizeof(float), biaya_rupiah);
}

void setupADC() {
  ADMUX = (1 << REFS0); // AVCC sebagai referensi
  ADCSRA = (1 << ADEN) | (1 << ADPS2) | (1 << ADPS1) | (1 << ADPS0); // Enable ADC, prescaler 128
}

int bacaADC(byte channel) {
  ADMUX = (ADMUX & 0xF0) | (channel & 0x07);
  ADCSRA |= (1 << ADSC);
  while (ADCSRA & (1 << ADSC)); // Tunggu konversi selesai
  return ADC;
}

void setup() {
  Serial.begin(9600);
  pinMode(pinRelay, OUTPUT);
  digitalWrite(pinRelay, LOW); // Relay ON awal

  muatEEPROM();
  energi_kwh_terakhir = energi_kwh;

  startMillis = millis();
  setupADC();
}

void loop() {
  if (millis() - startMillis >= interval) {
    int vmax = 0;
    int imax = 0;

    for (int i = 0; i < 50; i++) {
      int vSample = bacaADC(1); // A1 = tegangan
      int iSample = bacaADC(0); // A0 = arus

      if (vSample > vmax) vmax = vSample;
      if (iSample > imax) imax = iSample;

      delayMicroseconds(300);
    }

    vrms = (0.9743012 * vmax) - 499.81;
    irms = ((0.0111 * imax) - 5.673);
    daya = vrms * irms;

    Serial.print("VRMS = "); Serial.print(vrms);
    Serial.print(" | IRMS = "); Serial.print(irms);
    Serial.print(" | Daya = "); Serial.print(daya);
    Serial.print(" | kWh = "); Serial.print(energi_kwh, 4);
    Serial.print(" | Rp = "); Serial.println(biaya_rupiah, 2);

    bool kondisiBerbahaya = false;

    if (irms > batas_arus_short) {
      Serial.println("Proteksi: SHORT CIRCUIT!");
      kondisiBerbahaya = true;
    } else if (vrms > batas_overvoltage) {
      Serial.println("Proteksi: OVERVOLTAGE!");
      kondisiBerbahaya = true;
    } else if (vrms < batas_undervoltage) {
      Serial.println("Proteksi: UNDERVOLTAGE!");
      kondisiBerbahaya = true;
    } else if (abs(vrms - vrms_sebelumnya) > batas_fluktuasi) {
      Serial.println("Proteksi: FLUKTUASI TEGANGAN!");
      kondisiBerbahaya = true;
    }

    if (kondisiBerbahaya && !proteksiAktif) {
      proteksiAktif = true;
      digitalWrite(pinRelay, HIGH); // Relay OFF
      Serial.println("Relay OFF (Proteksi Aktif)");
      dalamPemulihan = true;
      indeksBuffer = 0;
    }

    if (dalamPemulihan) {
      statusBaik[indeksBuffer].teganganBaik = (vrms >= batas_undervoltage && vrms <= batas_overvoltage);
      statusBaik[indeksBuffer].arusBaik = (irms <= batas_arus_short);
      indeksBuffer++;

      if (indeksBuffer >= jumlahSampel) {
        int jumlahTeganganBaik = 0;
        int jumlahArusBaik = 0;

        for (int i = 0; i < jumlahSampel; i++) {
          if (statusBaik[i].teganganBaik) jumlahTeganganBaik++;
          if (statusBaik[i].arusBaik) jumlahArusBaik++;
        }

        float persenTeganganBaik = (jumlahTeganganBaik * 100.0) / jumlahSampel;
        float persenArusBaik = (jumlahArusBaik * 100.0) / jumlahSampel;

        Serial.print("Tegangan Stabil: "); Serial.print(persenTeganganBaik); Serial.print("% | ");
        Serial.print("Arus Stabil: "); Serial.print(persenArusBaik); Serial.println("%");

        if (persenTeganganBaik > 70.0 && persenArusBaik > 70.0) {
          digitalWrite(pinRelay, LOW); // Relay ON
          Serial.println("Relay ON (Tegangan dan Arus Stabil)");
          proteksiAktif = false;
          dalamPemulihan = false;
          indeksBuffer = 0; // Reset setelah sukses
        } else {
          Serial.println("Belum Stabil. Lanjut Monitoring...");
          // Jangan reset indeksBuffer di sini
        }
      }
    }

    if (!proteksiAktif) {
      energi_kwh += daya * (interval / 3600000.0); // Wh → kWh
      biaya_rupiah = energi_kwh * tarif_per_kwh;

      if (abs(energi_kwh - energi_kwh_terakhir) >= 0.01) {
        simpanEEPROM();
        energi_kwh_terakhir = energi_kwh;
      }
    }

    vrms_sebelumnya = vrms;
    startMillis = millis();
  }
}

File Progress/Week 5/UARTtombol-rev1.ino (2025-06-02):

#include <avr/io.h>
#include <EEPROM.h>
#include <stdlib.h>
#include <stdio.h>
#include <arduino.h>

const int pinRelay = 13;
const int interval = 20;
const int durasiPemulihan = 10000;
const int jumlahSampel = durasiPemulihan / interval;

const float batas_undervoltage = 150.0;
const float batas_overvoltage = 250.0;
const float batas_fluktuasi = 100.0;
const float batas_arus_short = 3.0;
const float tarif_per_kwh = 1352.0;

float vrms = 0;
float vrms_sebelumnya = 0;
float irms = 0;
float daya = 0;
float energi_kwh = 0;
float biaya_rupiah = 0;
float energi_kwh_terakhir = 0;

unsigned long startMillis;
bool proteksiAktif = false;
bool permintaanManualRelay = false;
bool baruReset = false; // FLAG RESET

struct StatusPemulihan {
  bool teganganBaik;
  bool arusBaik;
};

StatusPemulihan statusBaik[jumlahSampel];
int indeksBuffer = 0;
bool dalamPemulihan = false;

// UART
void UART_init() {
  UBRR0L = 103;
  UCSR0B = (1 << TXEN0) | (1 << RXEN0);
  UCSR0C = (1 << UCSZ01) | (1 << UCSZ00);
}

void UART_transmit(char data) {
  while (!(UCSR0A & (1 << UDRE0)));
  UDR0 = data;
}

void UART_print(const char* str) {
  while (*str) UART_transmit(*str++);
}

void UART_print_float(const char* label, float value, uint8_t precision) {
  char buffer[64];
  dtostrf(value, 0, precision, buffer);
  UART_print(label);
  UART_print(buffer);
  UART_print("\r\n");
}

void kirimDataPaket() {
  char buffer[64];
  sprintf(buffer, "V:%.2f;I:%.3f;E:%.4f;C:%.2f\r\n", vrms, irms, energi_kwh, biaya_rupiah);
  UART_print(buffer);
}

char UART_receive() {
  while (!(UCSR0A & (1 << RXC0)));
  return UDR0;
}

// EEPROM
void simpanEEPROM() {
  EEPROM.put(0, energi_kwh);
  EEPROM.put(sizeof(float), biaya_rupiah);
}

void muatEEPROM() {
  EEPROM.get(0, energi_kwh);
  EEPROM.get(sizeof(float), biaya_rupiah);
}

// ADC
void setupADC() {
  ADMUX = (1 << REFS0);
  ADCSRA = (1 << ADEN) | (1 << ADPS2) | (1 << ADPS1) | (1 << ADPS0);
}

int bacaADC(byte channel) {
  ADMUX = (ADMUX & 0xF0) | (channel & 0x07);
  ADCSRA |= (1 << ADSC);
  while (ADCSRA & (1 << ADSC));
  return ADC;
}

void setup() {
  UART_init();
  pinMode(pinRelay, OUTPUT);
  digitalWrite(pinRelay, LOW);

  muatEEPROM();
  energi_kwh_terakhir = energi_kwh;

  startMillis = millis();
  setupADC();

  UART_print("Sistem siap.\r\n");
  UART_print("Ketik 'N' = ON relay (cek stabilitas), 'F' = OFF manual, 'R' = reset energi.\r\n");
}

void loop() {
  if (UCSR0A & (1 << RXC0)) {
    char cmd = UART_receive();
    if (cmd == 'N' || cmd == 'n') {
      permintaanManualRelay = true;
      UART_print("Permintaan manual: Nyalakan relay (cek stabilitas 10 detik)\r\n");
      indeksBuffer = 0;
    } else if (cmd == 'F' || cmd == 'f') {
      if (!proteksiAktif) {
        digitalWrite(pinRelay, HIGH);
        UART_print("Relay dimatikan manual.\r\n");
      } else {
        UART_print("Tidak bisa dimatikan. Proteksi aktif.\r\n");
      }
    } else if (cmd == 'R' || cmd == 'r') {
      energi_kwh = 0;
      biaya_rupiah = 0;
      energi_kwh_terakhir = 0;
      simpanEEPROM();
      baruReset = true; // TANDAKAN RESET AKTIF
      UART_print("Energi dan biaya telah di-reset.\r\n");
    }
  }

  if (millis() - startMillis >= interval) {
    int vmax = 0;
    int imax = 0;

    for (int i = 0; i < 50; i++) {
      int vSample = bacaADC(1);
      int iSample = bacaADC(0);
      if (vSample > vmax) vmax = vSample;
      if (iSample > imax) imax = iSample;
      delayMicroseconds(300);
    }

    vrms = (0.978150 * vmax) - 499.81;
    irms = ((0.0111 * imax) - 5.673);
    daya = vrms * irms;

    UART_print_float("VRMS = ", vrms, 2);
    UART_print_float("kWh  = ", energi_kwh, 4);
    UART_print_float("Rp   = ", biaya_rupiah, 2);

    bool kondisiBerbahaya = false;

    if (irms > batas_arus_short) {
      UART_print("Proteksi: SHORT CIRCUIT!\r\n");
      kondisiBerbahaya = true;
    } else if (vrms > batas_overvoltage) {
      UART_print("Proteksi: OVERVOLTAGE!\r\n");
      kondisiBerbahaya = true;
    } else if (vrms < batas_undervoltage) {
      UART_print("Proteksi: UNDERVOLTAGE!\r\n");
      kondisiBerbahaya = true;
    } else if (abs(vrms - vrms_sebelumnya) > batas_fluktuasi) {
      UART_print("Proteksi: FLUKTUASI TEGANGAN!\r\n");
      kondisiBerbahaya = true;
    }

    if (kondisiBerbahaya && !proteksiAktif) {
      proteksiAktif = true;
      digitalWrite(pinRelay, HIGH);
      UART_print("Relay OFF (Proteksi Aktif)\r\n");
      dalamPemulihan = true;
      indeksBuffer = 0;
    }

    if (dalamPemulihan || permintaanManualRelay) {
      statusBaik[indeksBuffer].teganganBaik = (vrms >= batas_undervoltage && vrms <= batas_overvoltage);
      statusBaik[indeksBuffer].arusBaik = (irms <= batas_arus_short);
      indeksBuffer++;

      if (indeksBuffer >= jumlahSampel) {
        int jumlahTeganganBaik = 0, jumlahArusBaik = 0;
        for (int i = 0; i < jumlahSampel; i++) {
          if (statusBaik[i].teganganBaik) jumlahTeganganBaik++;
          if (statusBaik[i].arusBaik) jumlahArusBaik++;
        }

        float persenTeganganBaik = (jumlahTeganganBaik * 100.0) / jumlahSampel;
        float persenArusBaik = (jumlahArusBaik * 100.0) / jumlahSampel;

        UART_print_float("Tegangan Stabil = ", persenTeganganBaik, 1);
        UART_print_float("Arus Stabil     = ", persenArusBaik, 1);

        if (persenTeganganBaik > 70.0 && persenArusBaik > 70.0) {
          digitalWrite(pinRelay, LOW);
          UART_print("Relay ON (Tegangan dan Arus Stabil)\r\n");
          proteksiAktif = false;
          dalamPemulihan = false;
          permintaanManualRelay = false;
        } else {
          if (dalamPemulihan) {
            UART_print("Belum Stabil. Tetap Proteksi.\r\n");
          } else if (permintaanManualRelay) {
            UART_print("Permintaan manual ditolak: Tegangan/arus tidak stabil.\r\n");
            permintaanManualRelay = false;
          }
          indeksBuffer = 0;
        }
      }
    }

    if (!proteksiAktif && !baruReset) {
      energi_kwh += daya * (interval / 3600000.0);
      biaya_rupiah = energi_kwh * tarif_per_kwh;

      if (abs(energi_kwh - energi_kwh_terakhir) >= 0.01) {
        simpanEEPROM();
        energi_kwh_terakhir = energi_kwh;
      }
    } else if (baruReset) {
      // Satu siklus lewat, sekarang normal kembali
      baruReset = false;
    }

    kirimDataPaket();
    vrms_sebelumnya = vrms;
    startMillis = millis();
  }
}

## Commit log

2025-05-18 Add SCH, BOARD, 3d Hardware
    [LurCotte.kicad_pcb, LurCotte.kicad_sch]
2025-05-18 Progress Week 4 "Hardware & Mekanik"
    [BOX Lurcotte.ipt, Cover Lurcotte.ipt, Lucotte BOX.iam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]
2025-05-20 Add PNG Board
2025-06-02 Create Variabel Pin dan Parameter Sistem
2025-06-02 Create Deteksi Arus Pendek (Short Circuit)
2025-06-02 Create Saat Proteksi Aktif: Relay OFF dan Masuk Mode Pemulihan
2025-06-02 Create Jika Semua Aman: Relay ON dan Keluar dari Mode Pemulihan
2025-06-03 Add schematic
